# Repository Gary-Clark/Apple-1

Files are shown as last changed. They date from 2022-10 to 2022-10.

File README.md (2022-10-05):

# Apple-1

This is a project to mount a couple of EPROM's on the Apple-1 computer.

Gerbers for a simple PCB to mount two 2732 EPROMs selected via T & S select lines on the Apple-1 bus. If S is mapped to E000, BASIC can be burnt into the
EPROM meaning that BASIC is available without having to load from external storage.
The RAM normally located at E000 can then be mapped to the second bank of 4k giving more RAM for programs.

The .rar file contains the plot & drill files that can be uploaded to sites such as JCLPBC for production. The remaining files are Kicad files of the board.

Also included is a PCB for a two slot riser card so that the EPROM card and the Cassette interface can be fitted inside the case (given sufficient headroom). This card does not include any buffering but has been tested with an EPROM card and an ACI card installed.

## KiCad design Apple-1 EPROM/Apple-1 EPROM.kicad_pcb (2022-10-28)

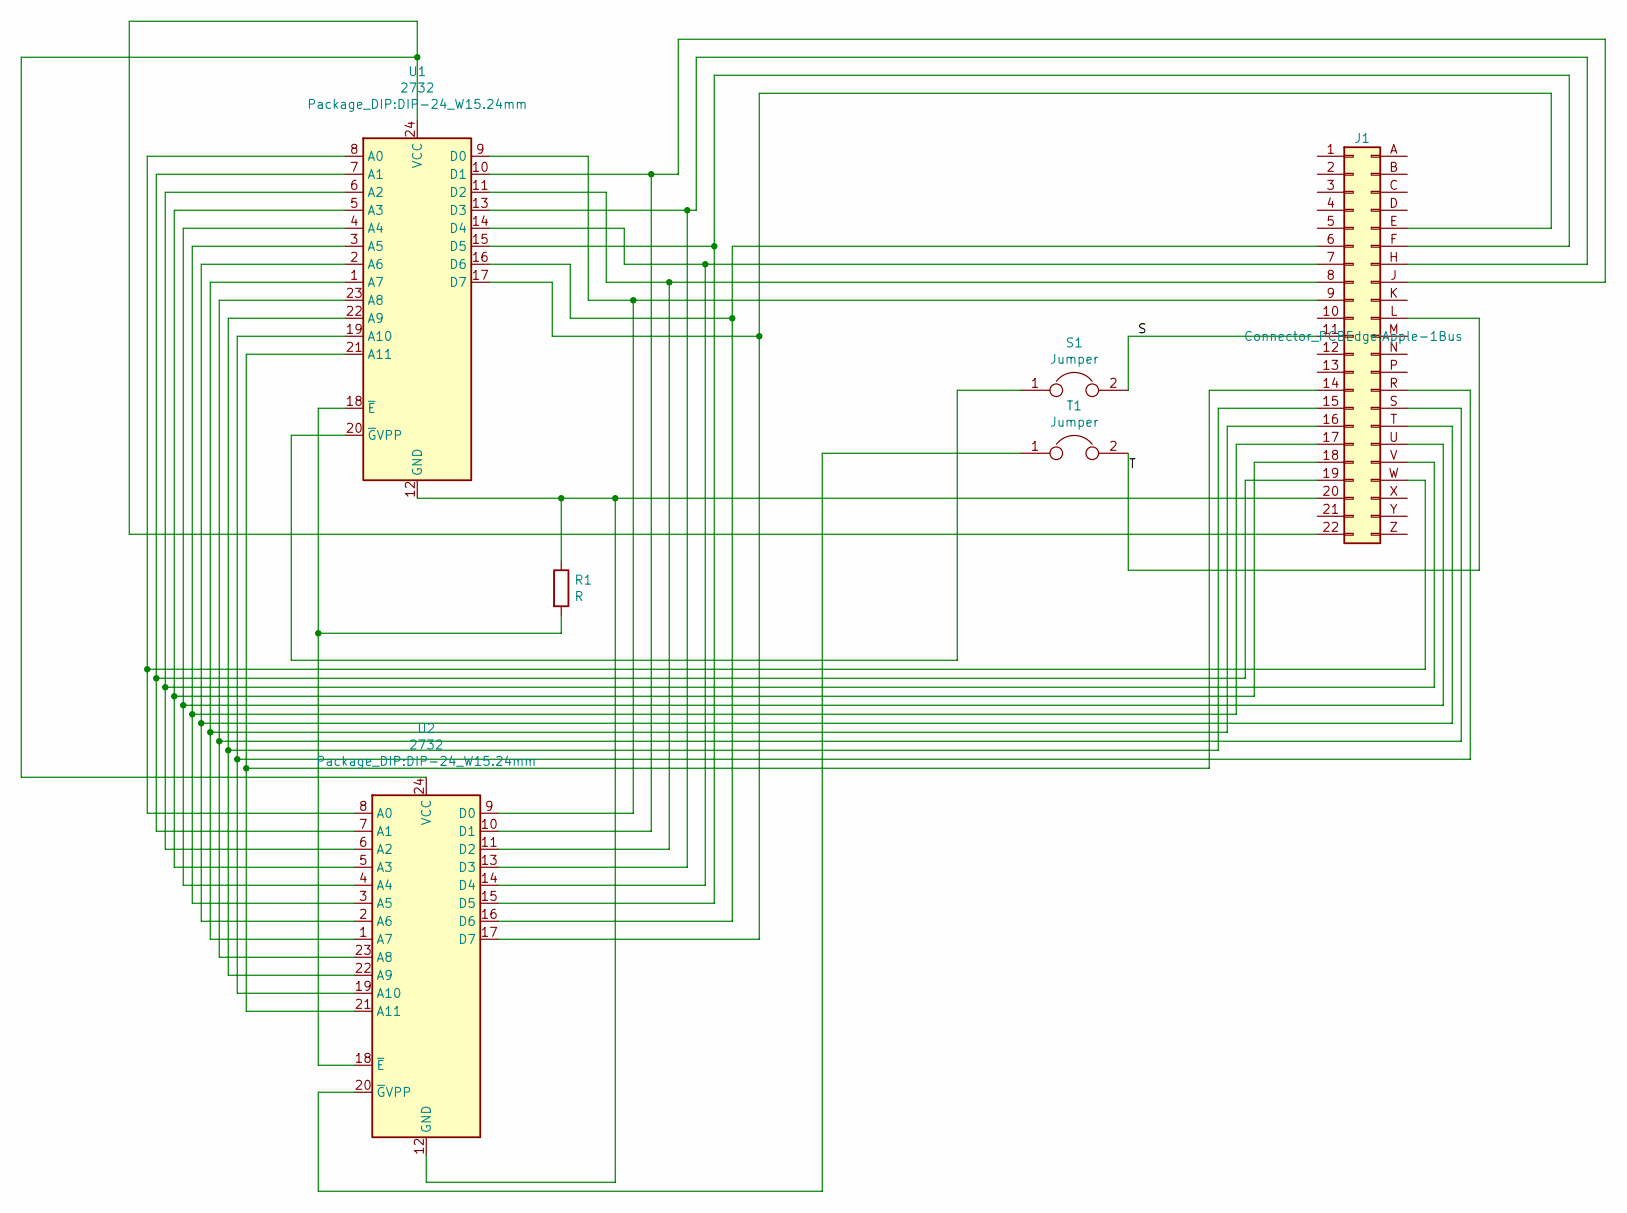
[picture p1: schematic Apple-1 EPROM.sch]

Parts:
J1: Conn_02x22_Apple_1-Connector_Generic_apple; Apple-1Bus
R1: R; R_Axial_DIN0411_L9.9mm_D3.6mm_P15.24mm_Horizontal
S1: Jumper; PinHeader_1x02_P2.54mm_Vertical
T1: Jumper; PinHeader_1x02_P2.54mm_Vertical
U1, U2: 2732; DIP-24_W15.24mm

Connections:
/S: J1.11, S1.2
/T: J1.L, T1.2
unnamed: J1.6, U1.16 (D6), U2.16 (D6)
unnamed: J1.7, U1.14 (D4), U2.14 (D4)
unnamed: J1.8, U1.11 (D2), U2.11 (D2)
unnamed: J1.9, U1.9 (D0), U2.9 (D0)
unnamed: J1.14, U1.21 (A11), U2.21 (A11)
unnamed: J1.15, U1.22 (A9), U2.22 (A9)
unnamed: J1.16, U1.1 (A7), U2.1 (A7)
unnamed: J1.17, U1.3 (A5), U2.3 (A5)
unnamed: J1.18, U1.5 (A3), U2.5 (A3)
unnamed: J1.19, U1.7 (A1), U2.7 (A1)
unnamed: J1.20, R1.1, U1.12 (GND), U2.12 (GND)
unnamed: J1.22, U1.24 (VCC), U2.24 (VCC)
unnamed: J1.E, U1.17 (D7), U2.17 (D7)
unnamed: J1.F, U1.15 (D5), U2.15 (D5)
unnamed: J1.H, U1.13 (D3), U2.13 (D3)
unnamed: J1.J, U1.10 (D1), U2.10 (D1)
unnamed: J1.R, U1.19 (A10), U2.19 (A10)
unnamed: J1.S, U1.23 (A8), U2.23 (A8)
unnamed: J1.T, U1.2 (A6), U2.2 (A6)
unnamed: J1.U, U1.4 (A4), U2.4 (A4)
unnamed: J1.V, U1.6 (A2), U2.6 (A2)
unnamed: J1.W, U1.8 (A0), U2.8 (A0)
unnamed: R1.2, U1.18 (~E), U2.18 (~E)
unnamed: S1.1, U1.20 (~G~VPP)
unnamed: T1.1, U2.20 (~G~VPP)

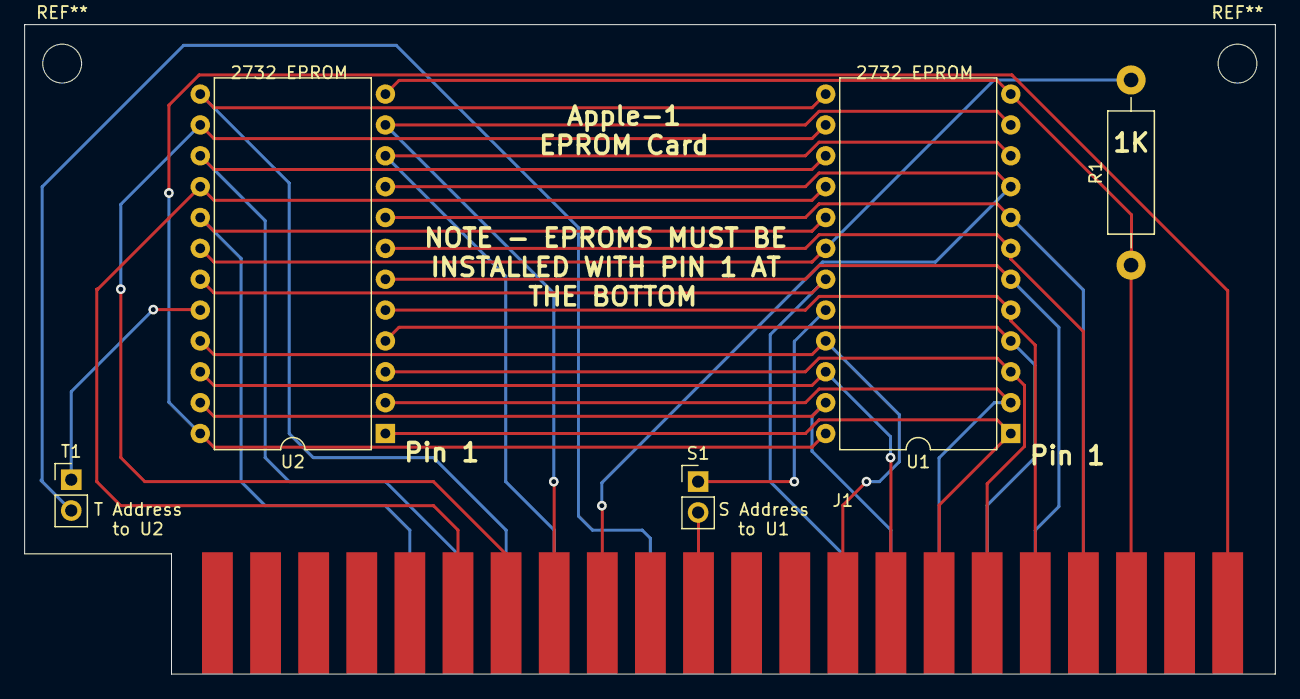
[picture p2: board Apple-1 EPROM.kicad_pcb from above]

Board: 2 copper layers, 103.0 x 53.5 mm, 6 parts (0 on the bottom side), 27 nets.

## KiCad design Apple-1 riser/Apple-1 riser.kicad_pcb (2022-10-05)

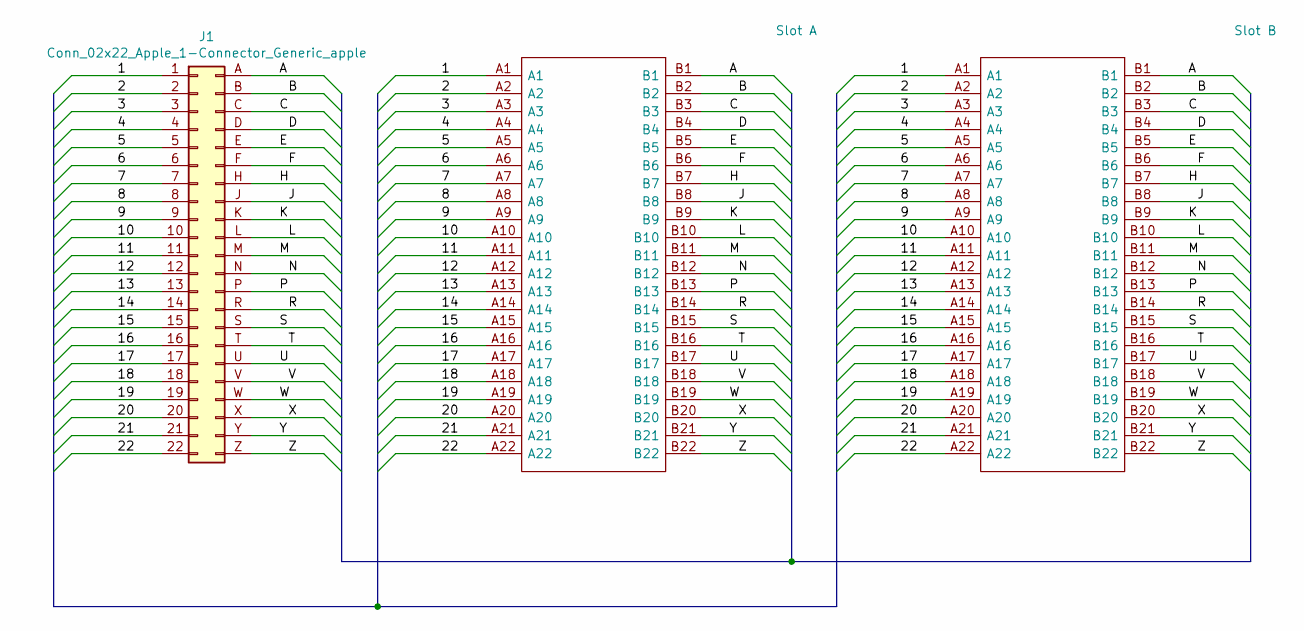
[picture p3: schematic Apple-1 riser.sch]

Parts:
J1: Conn_02x22_Apple_1-Connector_Generic_apple; Apple-1Bus
J2: Slot A; 305044521201; Manufacturer_Part_Number 305-044-521-201; Mouser Part Number 587-305-044-521-201
J3: Slot B; 305044521201; Manufacturer_Part_Number 305-044-521-201; Mouser Part Number 587-305-044-521-201

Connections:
/1: J1.1 (RF), J2.A1, J3.A1
/2: J1.2, J2.A2, J3.A2
/3: J1.3, J2.A3, J3.A3
/4: J1.4, J2.A4, J3.A4
/5: J1.5, J2.A5, J3.A5
/6: J1.6, J2.A6, J3.A6
/7: J1.7, J2.A7, J3.A7
/8: J1.8, J2.A8, J3.A8
/9: J1.9, J2.A9, J3.A9
/10: J1.10, J2.A10, J3.A10
/11: J1.11, J2.A11, J3.A11
/12: J1.12, J2.A12, J3.A12
/13: J1.13, J2.A13, J3.A13
/14: J1.14, J2.A14, J3.A14
/15: J1.15, J2.A15, J3.A15
/16: J1.16, J2.A16, J3.A16
/17: J1.17, J2.A17, J3.A17
/18: J1.18, J2.A18, J3.A18
/19: J1.19, J2.A19, J3.A19
/20: J1.20, J2.A20, J3.A20
/21: J1.21, J2.A21, J3.A21
/22: J1.22, J2.A22, J3.A22
/A: J1.A, J2.B1, J3.B1
/B: J1.B, J2.B2, J3.B2
/C: J1.C, J2.B3, J3.B3
/D: J1.D, J2.B4, J3.B4
/E: J1.E, J2.B5, J3.B5
/F: J1.F, J2.B6, J3.B6
/H: J1.H, J2.B7, J3.B7
/J: J1.J, J2.B8, J3.B8
/K: J1.K, J2.B9, J3.B9
/L: J1.L, J2.B10, J3.B10
/M: J1.M, J2.B11, J3.B11
/N: J1.N, J2.B12, J3.B12
/P: J1.P, J2.B13, J3.B13
/R: J1.R, J2.B14, J3.B14
/S: J1.S, J2.B15, J3.B15
/T: J1.T, J2.B16, J3.B16
/U: J1.U, J2.B17, J3.B17
/V: J1.V, J2.B18, J3.B18
/W: J1.W, J2.B19, J3.B19
/X: J1.X, J2.B20, J3.B20
/Y: J1.Y, J2.B21, J3.B21
/Z: J1.Z, J2.B22, J3.B22

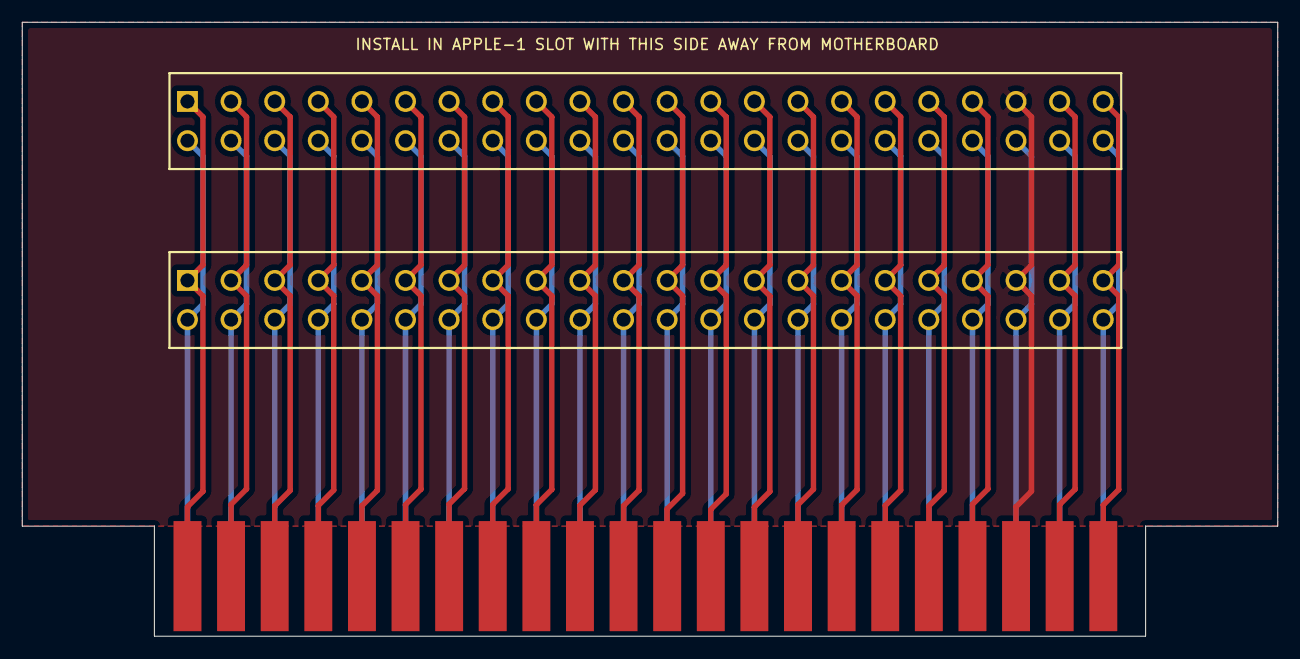
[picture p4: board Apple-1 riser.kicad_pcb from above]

Board: 2 copper layers, 114.0 x 55.8 mm, 3 parts (0 on the bottom side), 44 nets.
